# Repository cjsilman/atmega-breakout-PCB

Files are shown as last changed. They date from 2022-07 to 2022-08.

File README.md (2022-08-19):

# atmega-breakout-PCB
This PCB project is meant to replicate a simple atmega32u4 microcontroller board with GPIO pinouts. It contains a USB port for programming and powering.

As the idea of designing my own PCB always fascinated me, I thought it would be interesting to give designing one a shot!

While searching around the market for which MCU to use, I choose the ATMEGA32u4 as it comes with a pre-installed bootloader, allowing you to program it via the USB right from the start.
This MCU also came with USB support, something I wanted in my PCB. It was quite the learning process. I feel like I learned quite a bit that I want to share.



To begin with, you typically start by setting up the main components the MCU needs to function: it's power and crystal oscillator.

When designing the schematic for the VCC pins, it is best practice to place a 100nF decoupling capacitor for each pin along with a 10uF bulk decoupling capcitor to help with the stabilization of the input voltage.



For the crystal oscillator, you'll want to calculate the value of the decoupling capacitors associated with it. While it is standard practice to use 22pF capacitors, it is important to choose proper capacitor values to allow for more accurate and stable results from the crystal.

  - The capacitor values can be calculated from a formula like this:
    - C1, C2 = 2*Cload-2*Cstray

  - Cload, or the load capacitance, is retrieved from the datasheet of the specific crystal you choose.
  - Cstray, or the stray capacitance, is typically between a value of 3-5pF.
    - Cstray is the parasitic capacitance formed between two traces separated by a dielectric (in more layman terms, it is caused by a potential difference generated by current carrying traces running in close proximity to one another)



If you ever find yourself lost, the MCU datasheet typically has a lot of guidelines for when it comes to designing with that specific IC. Make sure to follow them.

I placed a GND plane on the entire bottom layer of my PCB. This allows for better signal integrity and more resistance to interference, it also allows you to create a via to ground wherever you need it.
     
  - Using one via per GND pin reduces the issue of potentially creating a ground loop and minimizes noise.

I discovered that USBs are typically designed with something known as "differential pairs"

  - On the schematic below, you can see D+ and D-, the postive and negative sign typically denote differential pairings
  - Differential pair PCB routing is used to create a balanced transmission system able to carry equal and opposite signals.
      - These two lines are usually of equal length
  - Having differential pairs also reduces any unwanted impedence



If you have any advice for me or would like to talk to me about certain design decisions feel free to give me a message! I am always looking to learn new things and improve my knowledge

# Full Schematic


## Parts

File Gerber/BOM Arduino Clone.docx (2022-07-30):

BOM Arduino Clone

Crystal 16 MHz 9pF - https://www.digikey.com/en/products/detail/aker-technology-corp/C3E-16-000-9-1015-X-R/14548523

- https://www.digikey.com/en/products/detail/w%C3%BCrth-elektronik/830100965009/13900163

Capacitors

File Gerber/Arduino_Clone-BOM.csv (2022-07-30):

Source: | G:\Desktop\KiCAD projects\Arduino_Clone\Arduino_Clone.kicad_sch
Date: | 7/26/2022 7:15:45 PM
Tool: | Eeschema (6.0.6)
Generator: | G:\Program Files\KiCad\6.0\bin\scripting\plugins/bom_csv_grouped_by_value_with_fp.py
Component Count: | 19
Ref | Qnty | Value | Cmp name | Footprint | Description | Vendor
C1, | 1 | 10uF | C | Capacitor_SMD:C_0805_2012Metric_Pad1.18x1.45mm_HandSolder | Unpolarized capacitor
C2, C3, C4, | 3 | 100nF | C | Capacitor_SMD:C_0805_2012Metric_Pad1.18x1.45mm_HandSolder | Unpolarized capacitor
C5, C6, | 2 | 22pF | C | Capacitor_SMD:C_0805_2012Metric_Pad1.18x1.45mm_HandSolder | Unpolarized capacitor
C7, | 1 | 1uF | C | Capacitor_SMD:C_0805_2012Metric_Pad1.18x1.45mm_HandSolder | Unpolarized capacitor
D1, | 1 | RED | LED | LED_SMD:LED_0805_2012Metric_Pad1.15x1.40mm_HandSolder | Light emitting diode
J1, | 1 | Conn_01x09_Female | Conn_01x09_Female | Connector_PinSocket_2.54mm:PinSocket_1x09_P2.54mm_Vertical | Generic connector, single row, 01x09, script generated (kicad-library-utils/schlib/autogen/connector/)
J2, | 1 | Conn_01x08_Female | Conn_01x08_Female | Connector_PinSocket_2.54mm:PinSocket_1x08_P2.54mm_Vertical | Generic connector, single row, 01x08, script generated (kicad-library-utils/schlib/autogen/connector/)
J3, | 1 | Conn_01x12_Female | Conn_01x12_Female | Connector_PinSocket_2.54mm:PinSocket_1x12_P2.54mm_Vertical | Generic connector, single row, 01x12, script generated (kicad-library-utils/schlib/autogen/connector/)
J4, | 1 | USB_B_Micro | USB_B_Micro | Connector_USB:USB_Micro-B_Wuerth_629105150521 | USB Micro Type B connector
R1, | 1 | 10k | R | Resistor_SMD:R_0805_2012Metric_Pad1.20x1.40mm_HandSolder | Resistor
R2, | 1 | 1k5 | R | Resistor_SMD:R_0805_2012Metric_Pad1.20x1.40mm_HandSolder | Resistor
R3, R4, | 2 | 22R | R | Resistor_SMD:R_0805_2012Metric_Pad1.20x1.40mm_HandSolder | Resistor
SW1, | 1 | SW_Push | SW_Push | Button_Switch_SMD:SW_Push_1P1T_NO_6x6mm_H9.5mm | Push button switch, generic, two pins
U1, | 1 | ATmega32U4-A | ATmega32U4-A | Package_QFP:TQFP-44_10x10mm_P0.8mm | 16MHz, 32kB Flash, 2.5kB SRAM, 1kB EEPROM, USB 2.0, TQFP-44
Y1, | 1 | 16MHz | Crystal_GND24 | Crystal:Crystal_SMD_3225-4Pin_3.2x2.5mm | Four pin crystal, GND on pins 2 and 4

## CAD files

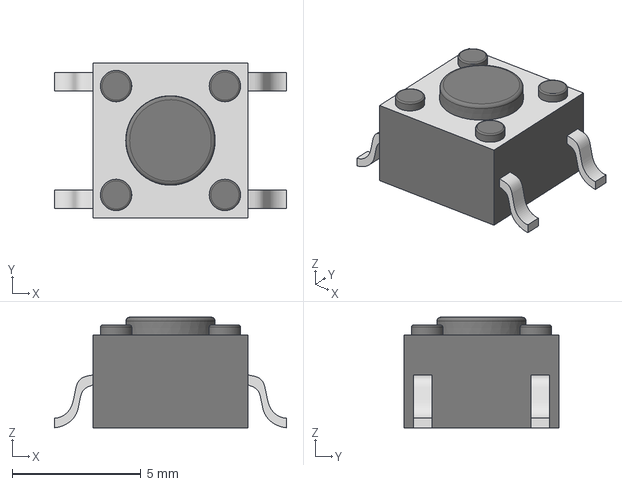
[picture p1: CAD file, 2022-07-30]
3D Models/Tactal Switch - SMD (6mmx 6mmx 4.3mm) - Marked.stp
9.02 x 6.03 x 4.30 mm

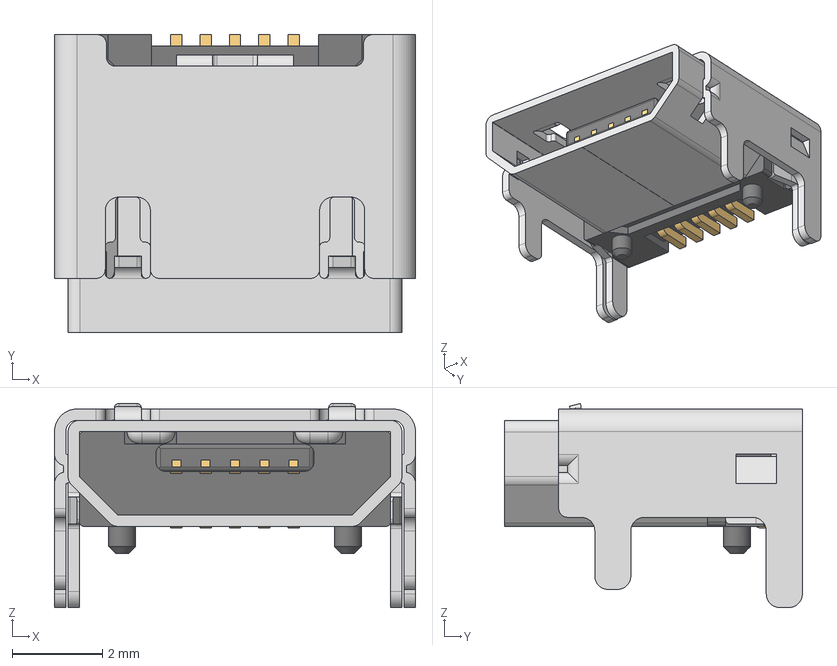
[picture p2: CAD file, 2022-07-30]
3D Models/MicroUSB.stp
8.00 x 6.60 x 4.52 mm
629105150521_Housing
629105150521_Pin1 x 4
629105150521_Pin2
629105150521_Shielding2
629105150521_Shielding

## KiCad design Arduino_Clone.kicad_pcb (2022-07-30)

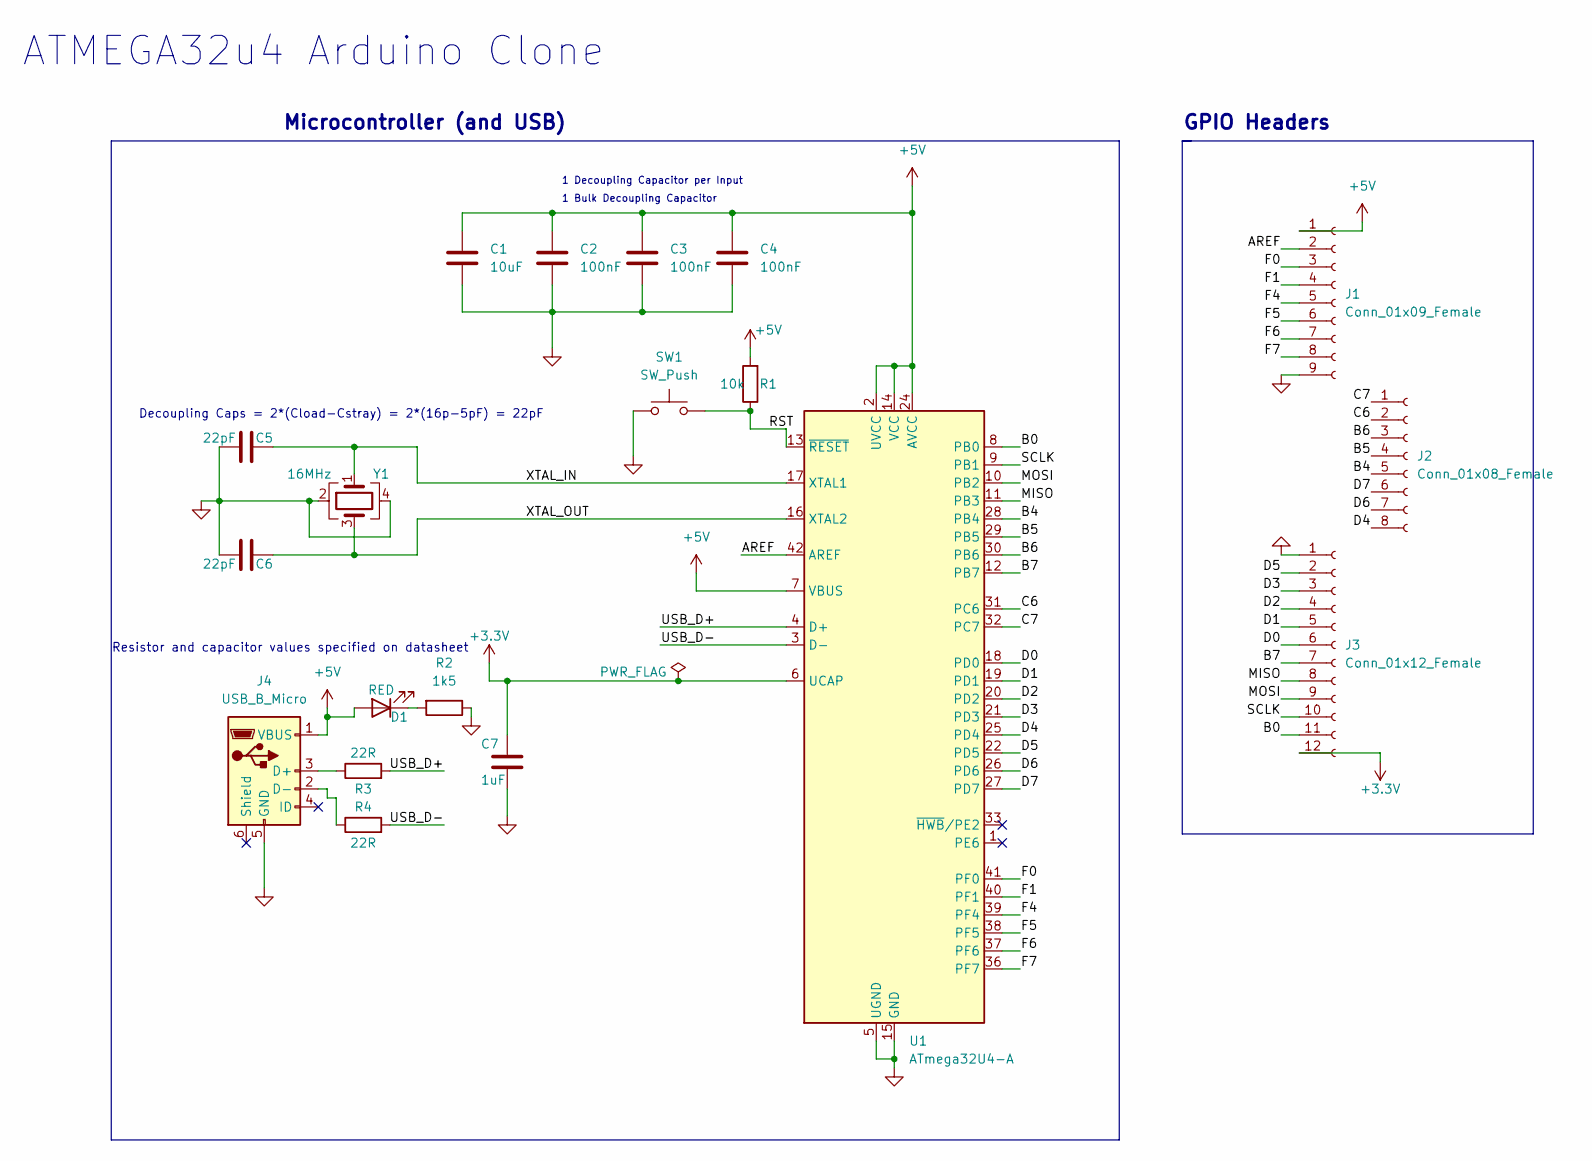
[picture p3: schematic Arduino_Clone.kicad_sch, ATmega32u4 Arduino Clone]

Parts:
C1: 10uF; C_0805_2012Metric_Pad1.18x1.45mm_HandSolder
C2, C3, C4: 100nF; C_0805_2012Metric_Pad1.18x1.45mm_HandSolder
C5, C6: 22pF; C_0805_2012Metric_Pad1.18x1.45mm_HandSolder
C7: 1uF; C_0805_2012Metric_Pad1.18x1.45mm_HandSolder
D1: RED; LED_0805_2012Metric_Pad1.15x1.40mm_HandSolder
J1: Conn_01x09_Female; PinSocket_1x09_P2.54mm_Vertical
J2: Conn_01x08_Female; PinSocket_1x08_P2.54mm_Vertical
J3: Conn_01x12_Female; PinSocket_1x12_P2.54mm_Vertical
J4: USB_B_Micro; USB_Micro-B_Wuerth_629105150521
R1: 10k; R_0805_2012Metric_Pad1.20x1.40mm_HandSolder
R2: 1k5; R_0805_2012Metric_Pad1.20x1.40mm_HandSolder
R3, R4: 22R; R_0805_2012Metric_Pad1.20x1.40mm_HandSolder
SW1: SW_Push; SW_Push_1P1T_NO_6x6mm_H9.5mm
U1: ATmega32U4-A; TQFP-44_10x10mm_P0.8mm
Y1: 16MHz; Crystal_SMD_3225-4Pin_3.2x2.5mm

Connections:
+3.3V: C7.1, J3.12, U1.6 (UCAP)
+5V: C1.1, C2.1, C3.1, C4.1, D1.2 (A), J1.1, J4.1 (VBUS), R1.2, U1.2 (UVCC), U1.7 (VBUS), U1.14 (VCC), U1.24 (AVCC), U1.34 (VCC), U1.44 (AVCC)
/AREF: J1.2, U1.42 (AREF)
/B0: J3.11, U1.8 (PB0)
/B4: J2.5, U1.28 (PB4)
/B5: J2.4, U1.29 (PB5)
/B6: J2.3, U1.30 (PB6)
/B7: J3.7, U1.12 (PB7)
/C6: J2.2, U1.31 (PC6)
/C7: J2.1, U1.32 (PC7)
/D0: J3.6, U1.18 (PD0)
/D1: J3.5, U1.19 (PD1)
/D2: J3.4, U1.20 (PD2)
/D3: J3.3, U1.21 (PD3)
/D4: J2.8, U1.25 (PD4)
/D5: J3.2, U1.22 (PD5)
/D6: J2.7, U1.26 (PD6)
/D7: J2.6, U1.27 (PD7)
/F0: J1.3, U1.41 (PF0)
/F1: J1.4, U1.40 (PF1)
/F4: J1.5, U1.39 (PF4)
/F5: J1.6, U1.38 (PF5)
/F6: J1.7, U1.37 (PF6)
/F7: J1.8, U1.36 (PF7)
/MISO: J3.8, U1.11 (PB3)
/MOSI: J3.9, U1.10 (PB2)
/RST: R1.1, SW1.2, U1.13 (~RESET)
/SCLK: J3.10, U1.9 (PB1)
/USB_D+: R3.2, U1.4 (D+)
/USB_D-: R4.2, U1.3 (D-)
/XTAL_IN: C5.2, U1.17 (XTAL1), Y1.1
/XTAL_OUT: C6.2, U1.16 (XTAL2), Y1.3
GND: C1.2, C2.2, C3.2, C4.2, C5.1, C6.1, C7.2, J1.9, J3.1, J4.5 (GND), R2.1, SW1.1, U1.5 (UGND), U1.15 (GND), U1.23 (GND), U1.35 (GND), U1.43 (GND), Y1.2, Y1.4
unnamed: D1.1 (K), R2.2
unnamed: J4.2 (D-), R4.1
unnamed: J4.3 (D+), R3.1

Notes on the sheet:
1 Bulk Decoupling Capacitor
Resistor and capacitor values specified on datasheet
GPIO Headers
ATMEGA32u4 Arduino Clone
1 Decoupling Capacitor per Input
Microcontroller (and USB)
Decoupling Caps = 2*(Cload-Cstray) = 2*(16p-5pF) = 22pF

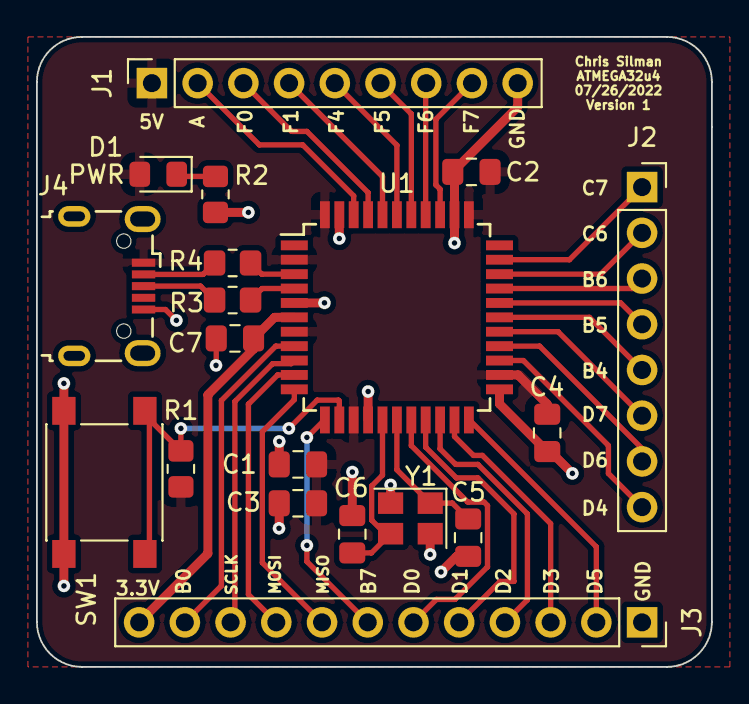
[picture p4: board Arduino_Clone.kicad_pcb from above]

Board: 2 copper layers, 37.5 x 35.0 mm, 19 parts (0 on the bottom side), 36 nets.
